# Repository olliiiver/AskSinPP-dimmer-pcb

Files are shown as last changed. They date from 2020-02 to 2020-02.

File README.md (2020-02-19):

# Homematic 5-channel LED dimmer PCB for Arduino using CC1101 (KiCad)

Arduino sketch can be found here:

https://github.com/olliiiver/AskSinPP-rgbwwcw-dimmer

## Features

- 12-24 volt
- 256-step 97 kHz PWM
- TTH or SMD for filter capacitors 

## BOM

- PCA9634PW
- Arduino Pro Mini https://store.arduino.cc/arduino-pro-mini
- CC1101 board (from eBay)
- N-Channel MOSFET (IRL540N 30A 100V)
- Recom R-78E5.0-0.5
- AMS1117-3.3
- 10K resistors
- 100 nF / 10 uF capacitors

## TODO

- Add ground pad

## Images

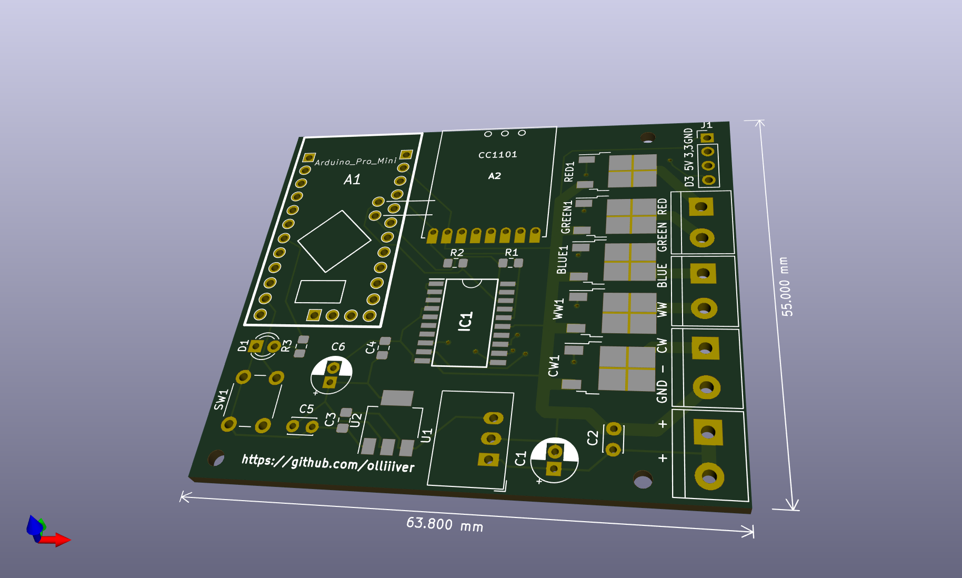
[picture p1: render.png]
KiCad render


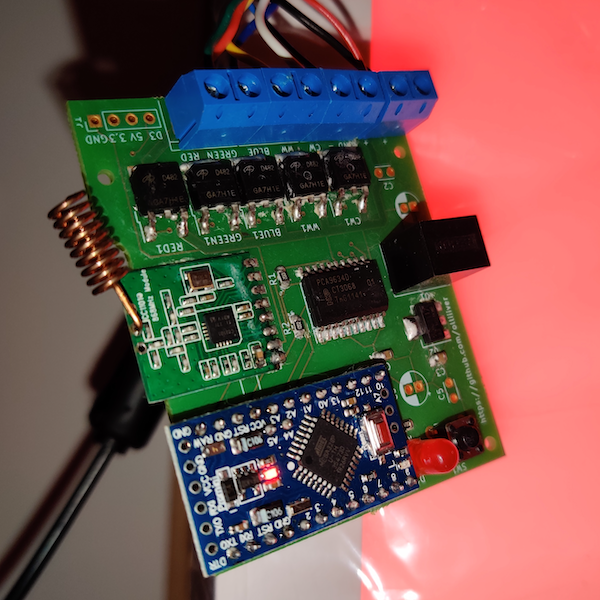
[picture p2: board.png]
board photo


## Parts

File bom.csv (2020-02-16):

Reference | Value | Footprint | Datasheet | Description | Height | Manufacturer_Name | Manufacturer_Part_Number | Mouser Part Number | Mouser Price/Stock | RS Part Number | RS Price/Stock | Allied Price/Stock | Allied_Number
C1 | 10µF | Capacitor_SMD:C_0805_2012Metric_Pad1.15x1.40mm_HandSolder | ~
U1 | R-78E5.0-0.5 | Converter_DCDC:Converter_DCDC_RECOM_R-78E-0.5_THT | https://www.recom-power.com/pdf/Innoline/R-78Exx-0.5.pdf
C2 | 10µF | Capacitor_SMD:C_0805_2012Metric_Pad1.15x1.40mm_HandSolder | ~
U2 | AMS1117-3.3 | Package_TO_SOT_SMD:SOT-223-3_TabPin2 | http://www.advanced-monolithic.com/pdf/ds1117.pdf
C3 | 10µF | Capacitor_SMD:C_0805_2012Metric_Pad1.15x1.40mm_HandSolder | ~
P1 | Power | TerminalBlock:TerminalBlock_bornier-2_P5.08mm | ~
A2 | CC1101 | foo:cc1101
A1 | Arduino_Pro_Mini | foo:Arduino_Pro_Mini | https://www.arduino.cc/en/Main/ArduinoBoardProMini
IC1 | PCA9634PW | foo:PCA9634PW |  | PCA9634PW, LED Driver 16-Segments, 3.3, 5V, 20-Pin TSSOP | 1.1 | Nexperia | PCA9634PW | 771-PCA9634PW | https://www.mouser.com/Search/Refine.aspx?Keyword=771-PCA9634PW | 511030 | http://uk.rs-online.com/web/p/led-display-drivers/511030/?source=DS
M1 | IRL540NPBF | TO254P469X1042X1967-3P |  | N-channel MOSFET,IRL540N 30A 100V | 4.69 | International Rectifier | IRL540NPBF | 942-IRL540NPBF | http://www.mouser.com/Search/ProductDetail.aspx?qs=9%252bKlkBgLFf0uZBCvyYsQoQ%3d%3d | 2509056052 | http://uk.rs-online.com/web/p/products/2509056052 | http://www.alliedelec.com/international-rectifier-irl540npbf/70017094/ | 70017094
P2 | Output1 | TerminalBlock:TerminalBlock_bornier-2_P5.08mm | ~
M2 | IRL540NPBF | TO254P469X1042X1967-3P |  | N-channel MOSFET,IRL540N 30A 100V | 4.69 | International Rectifier | IRL540NPBF | 942-IRL540NPBF | http://www.mouser.com/Search/ProductDetail.aspx?qs=9%252bKlkBgLFf0uZBCvyYsQoQ%3d%3d | 2509056052 | http://uk.rs-online.com/web/p/products/2509056052 | http://www.alliedelec.com/international-rectifier-irl540npbf/70017094/ | 70017094
M3 | IRL540NPBF | TO254P469X1042X1967-3P |  | N-channel MOSFET,IRL540N 30A 100V | 4.69 | International Rectifier | IRL540NPBF | 942-IRL540NPBF | http://www.mouser.com/Search/ProductDetail.aspx?qs=9%252bKlkBgLFf0uZBCvyYsQoQ%3d%3d | 2509056052 | http://uk.rs-online.com/web/p/products/2509056052 | http://www.alliedelec.com/international-rectifier-irl540npbf/70017094/ | 70017094
M4 | IRL540NPBF | TO254P469X1042X1967-3P |  | N-channel MOSFET,IRL540N 30A 100V | 4.69 | International Rectifier | IRL540NPBF | 942-IRL540NPBF | http://www.mouser.com/Search/ProductDetail.aspx?qs=9%252bKlkBgLFf0uZBCvyYsQoQ%3d%3d | 2509056052 | http://uk.rs-online.com/web/p/products/2509056052 | http://www.alliedelec.com/international-rectifier-irl540npbf/70017094/ | 70017094
M5 | IRL540NPBF | TO254P469X1042X1967-3P |  | N-channel MOSFET,IRL540N 30A 100V | 4.69 | International Rectifier | IRL540NPBF | 942-IRL540NPBF | http://www.mouser.com/Search/ProductDetail.aspx?qs=9%252bKlkBgLFf0uZBCvyYsQoQ%3d%3d | 2509056052 | http://uk.rs-online.com/web/p/products/2509056052 | http://www.alliedelec.com/international-rectifier-irl540npbf/70017094/ | 70017094
P3 | Output1 | TerminalBlock:TerminalBlock_bornier-2_P5.08mm | ~
P4 | Output1 | TerminalBlock:TerminalBlock_bornier-2_P5.08mm | ~
R1 | 10K |  | ~
R2 | 10K |  | ~

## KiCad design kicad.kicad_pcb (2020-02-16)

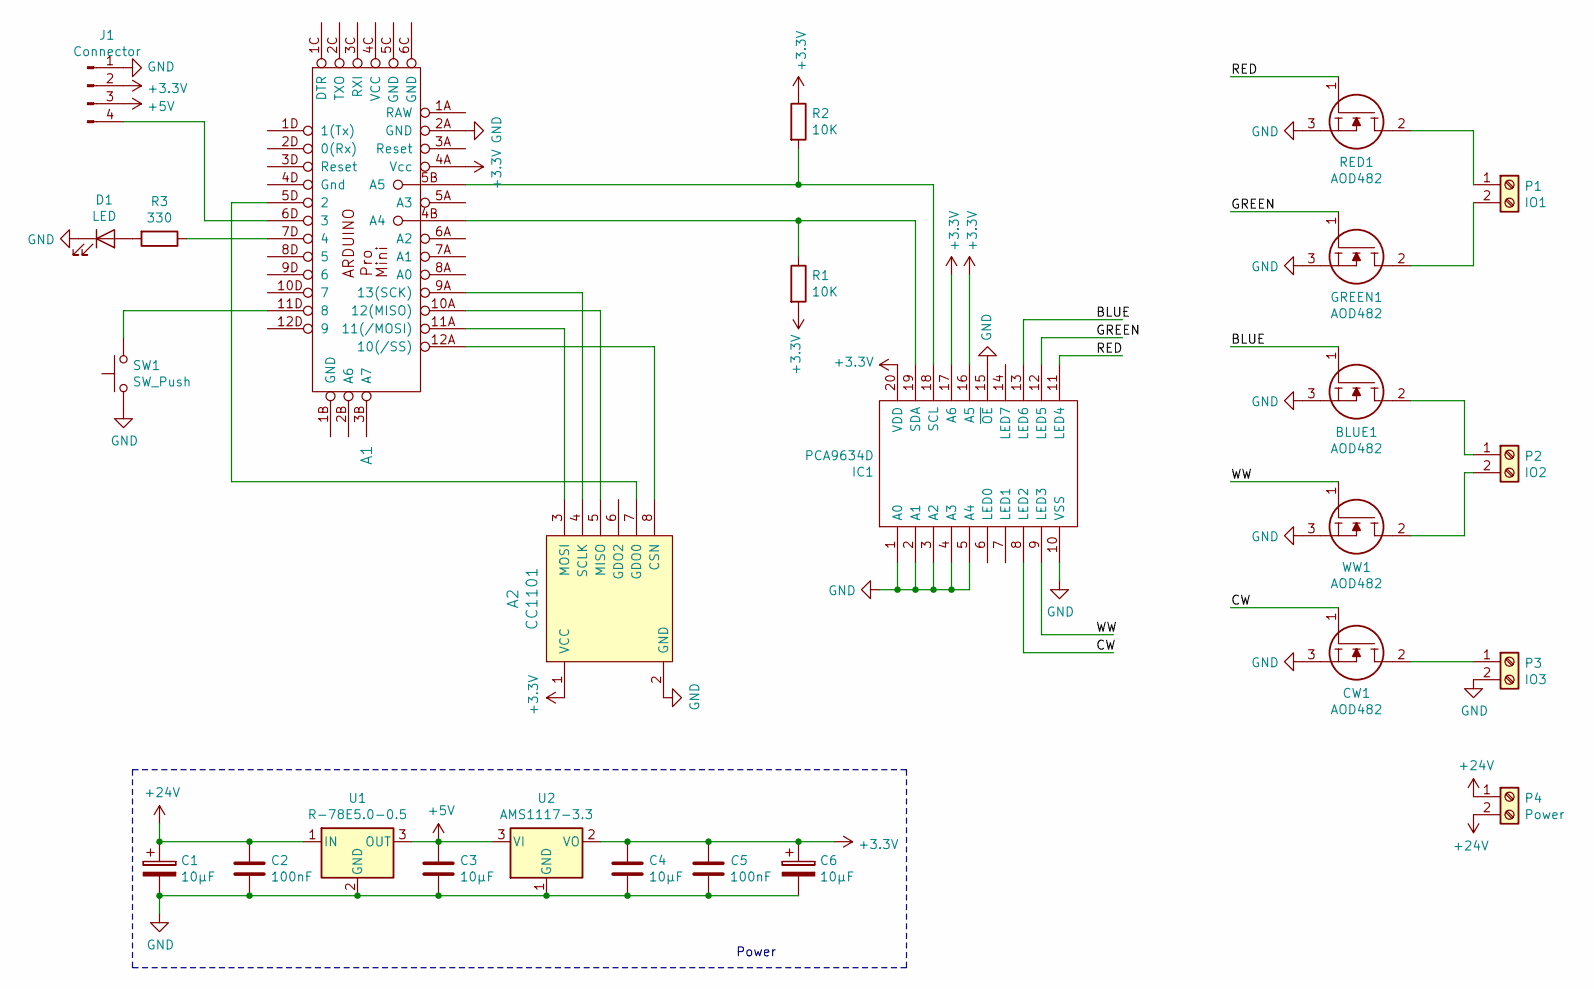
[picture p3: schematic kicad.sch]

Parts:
A1: Arduino_Pro_Mini
A2: CC1101; cc1101
BLUE1: AOD482; TO-252-2; Manufacturer_Part_Number IRL540NPBF; Mouser Part Number 942-IRL540NPBF
C1, C6: 10µF; CP_Radial_D5.0mm_P2.00mm
C2, C5: 100nF; C_Disc_D3.0mm_W2.0mm_P2.50mm
C3, C4: 10µF; C_0805_2012Metric_Pad1.15x1.40mm_HandSolder
CW1: AOD482; TO-252-2; Manufacturer_Part_Number IRL540NPBF; Mouser Part Number 942-IRL540NPBF
D1: LED; LED_D3.0mm
GREEN1: AOD482; TO-252-2; Manufacturer_Part_Number IRL540NPBF; Mouser Part Number 942-IRL540NPBF
IC1: PCA9634D; Manufacturer_Part_Number PCA9634D; Mouser Part Number 771-PCA9634D
J1: Connector; PinHeader_1x04_P2.54mm_Vertical
P1: IO1; TerminalBlock_bornier-2_P5.08mm
P2: IO2; TerminalBlock_bornier-2_P5.08mm
P3: IO3; TerminalBlock_bornier-2_P5.08mm
P4: Power; TerminalBlock_bornier-2_P5.08mm
R1, R2: 10K; R_0805_2012Metric_Pad1.15x1.40mm_HandSolder
R3: 330; R_0805_2012Metric_Pad1.15x1.40mm_HandSolder
RED1: AOD482; TO-252-2; Manufacturer_Part_Number IRL540NPBF; Mouser Part Number 942-IRL540NPBF
SW1: SW_Push; SW_PUSH_6mm
U1: R-78E5.0-0.5; Converter_DCDC_RECOM_R-78E-0.5_THT
U2: AMS1117-3.3; SOT-223-3_TabPin2
WW1: AOD482; TO-252-2; Manufacturer_Part_Number IRL540NPBF; Mouser Part Number 942-IRL540NPBF

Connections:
+3V3: A1.4A (Vcc), A2.1 (VCC), C4.1, C5.1, C6.1, IC1.16 (A5), IC1.17 (A6), IC1.20 (VDD), J1.2, R1.2, R2.1, U2.2 (VO)
+5V: C3.1, J1.3, U1.3 (OUT), U2.3 (VI)
+24V: C1.1, C2.1, P4.1, P4.2, U1.1 (IN)
/BLUE: BLUE1.1, IC1.13 (LED6)
/CW: CW1.1, IC1.8 (LED2)
/GREEN: GREEN1.1, IC1.12 (LED5)
/RED: IC1.11 (LED4), RED1.1
/WW: IC1.9 (LED3), WW1.1
GND: A1.2A (GND), A2.2 (GND), BLUE1.3, C1.2, C2.2, C3.2, C4.2, C5.2, C6.2, CW1.3, D1.1 (K), GREEN1.3, IC1.1 (A0), IC1.2 (A1), IC1.3 (A2), IC1.4 (A3), IC1.5 (A4), IC1.10 (VSS), IC1.15 (~OE), J1.1, P3.2, RED1.3, SW1.1, U1.2 (GND), U2.1 (GND), WW1.3
unnamed: A1.4B (A4), IC1.19 (SDA), R1.1
unnamed: A1.5B (A5), IC1.18 (SCL), R2.2
unnamed: A1.5D (2), A2.7 (GDO0)
unnamed: A1.6D (3), J1.4
unnamed: A1.7D (4), R3.1
unnamed: A1.9A (13(SCK)), A2.4 (SCLK)
unnamed: A1.10A (12(MISO)), A2.5 (MISO)
unnamed: A1.11A (11(/MOSI)), A2.3 (MOSI)
unnamed: A1.11D (8), SW1.2
unnamed: A1.12A (10(/SS)), A2.8 (CSN)
unnamed: BLUE1.2, P2.1
unnamed: CW1.2, P3.1
unnamed: D1.2 (A), R3.2
unnamed: GREEN1.2, P1.2
unnamed: P1.1, RED1.2
unnamed: P2.2, WW1.2

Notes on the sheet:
Power

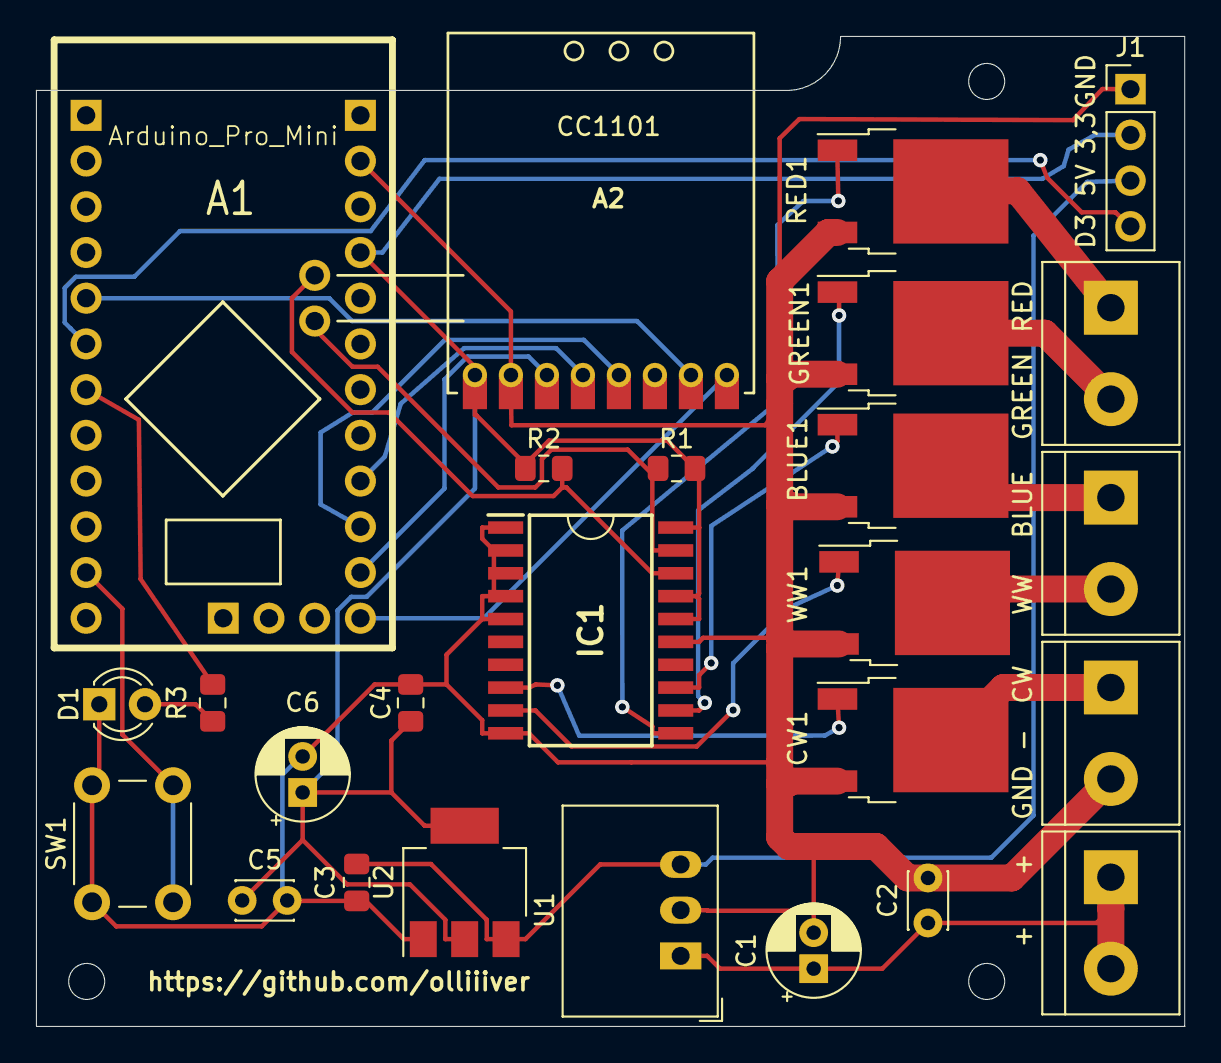
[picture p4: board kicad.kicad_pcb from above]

Board: 2 copper layers, 63.8 x 55.0 mm, 29 parts (0 on the bottom side), 25 nets.

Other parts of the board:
MO1, MO2, MO3: MountingHole_2mm
